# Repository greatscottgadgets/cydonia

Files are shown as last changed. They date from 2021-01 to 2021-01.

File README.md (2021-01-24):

# Cydonia

a 2.4 GHz receiver front-end based on [Quince](https://github.com/greatfet-hardware/quince)

## Project Status

Initial prototypes have not yet been assembled.

## Viewing or Modifying the Design

Required KiCad dependency:

https://github.com/greatscottgadgets/gsg-kicad-lib

If you are using git, the preferred way to install gsg-kicad-lib is to use the
submodule:

```
git submodule init && git submodule update
```

## Hardware Development Notes

See [Quince](https://github.com/greatfet-hardware/quince).

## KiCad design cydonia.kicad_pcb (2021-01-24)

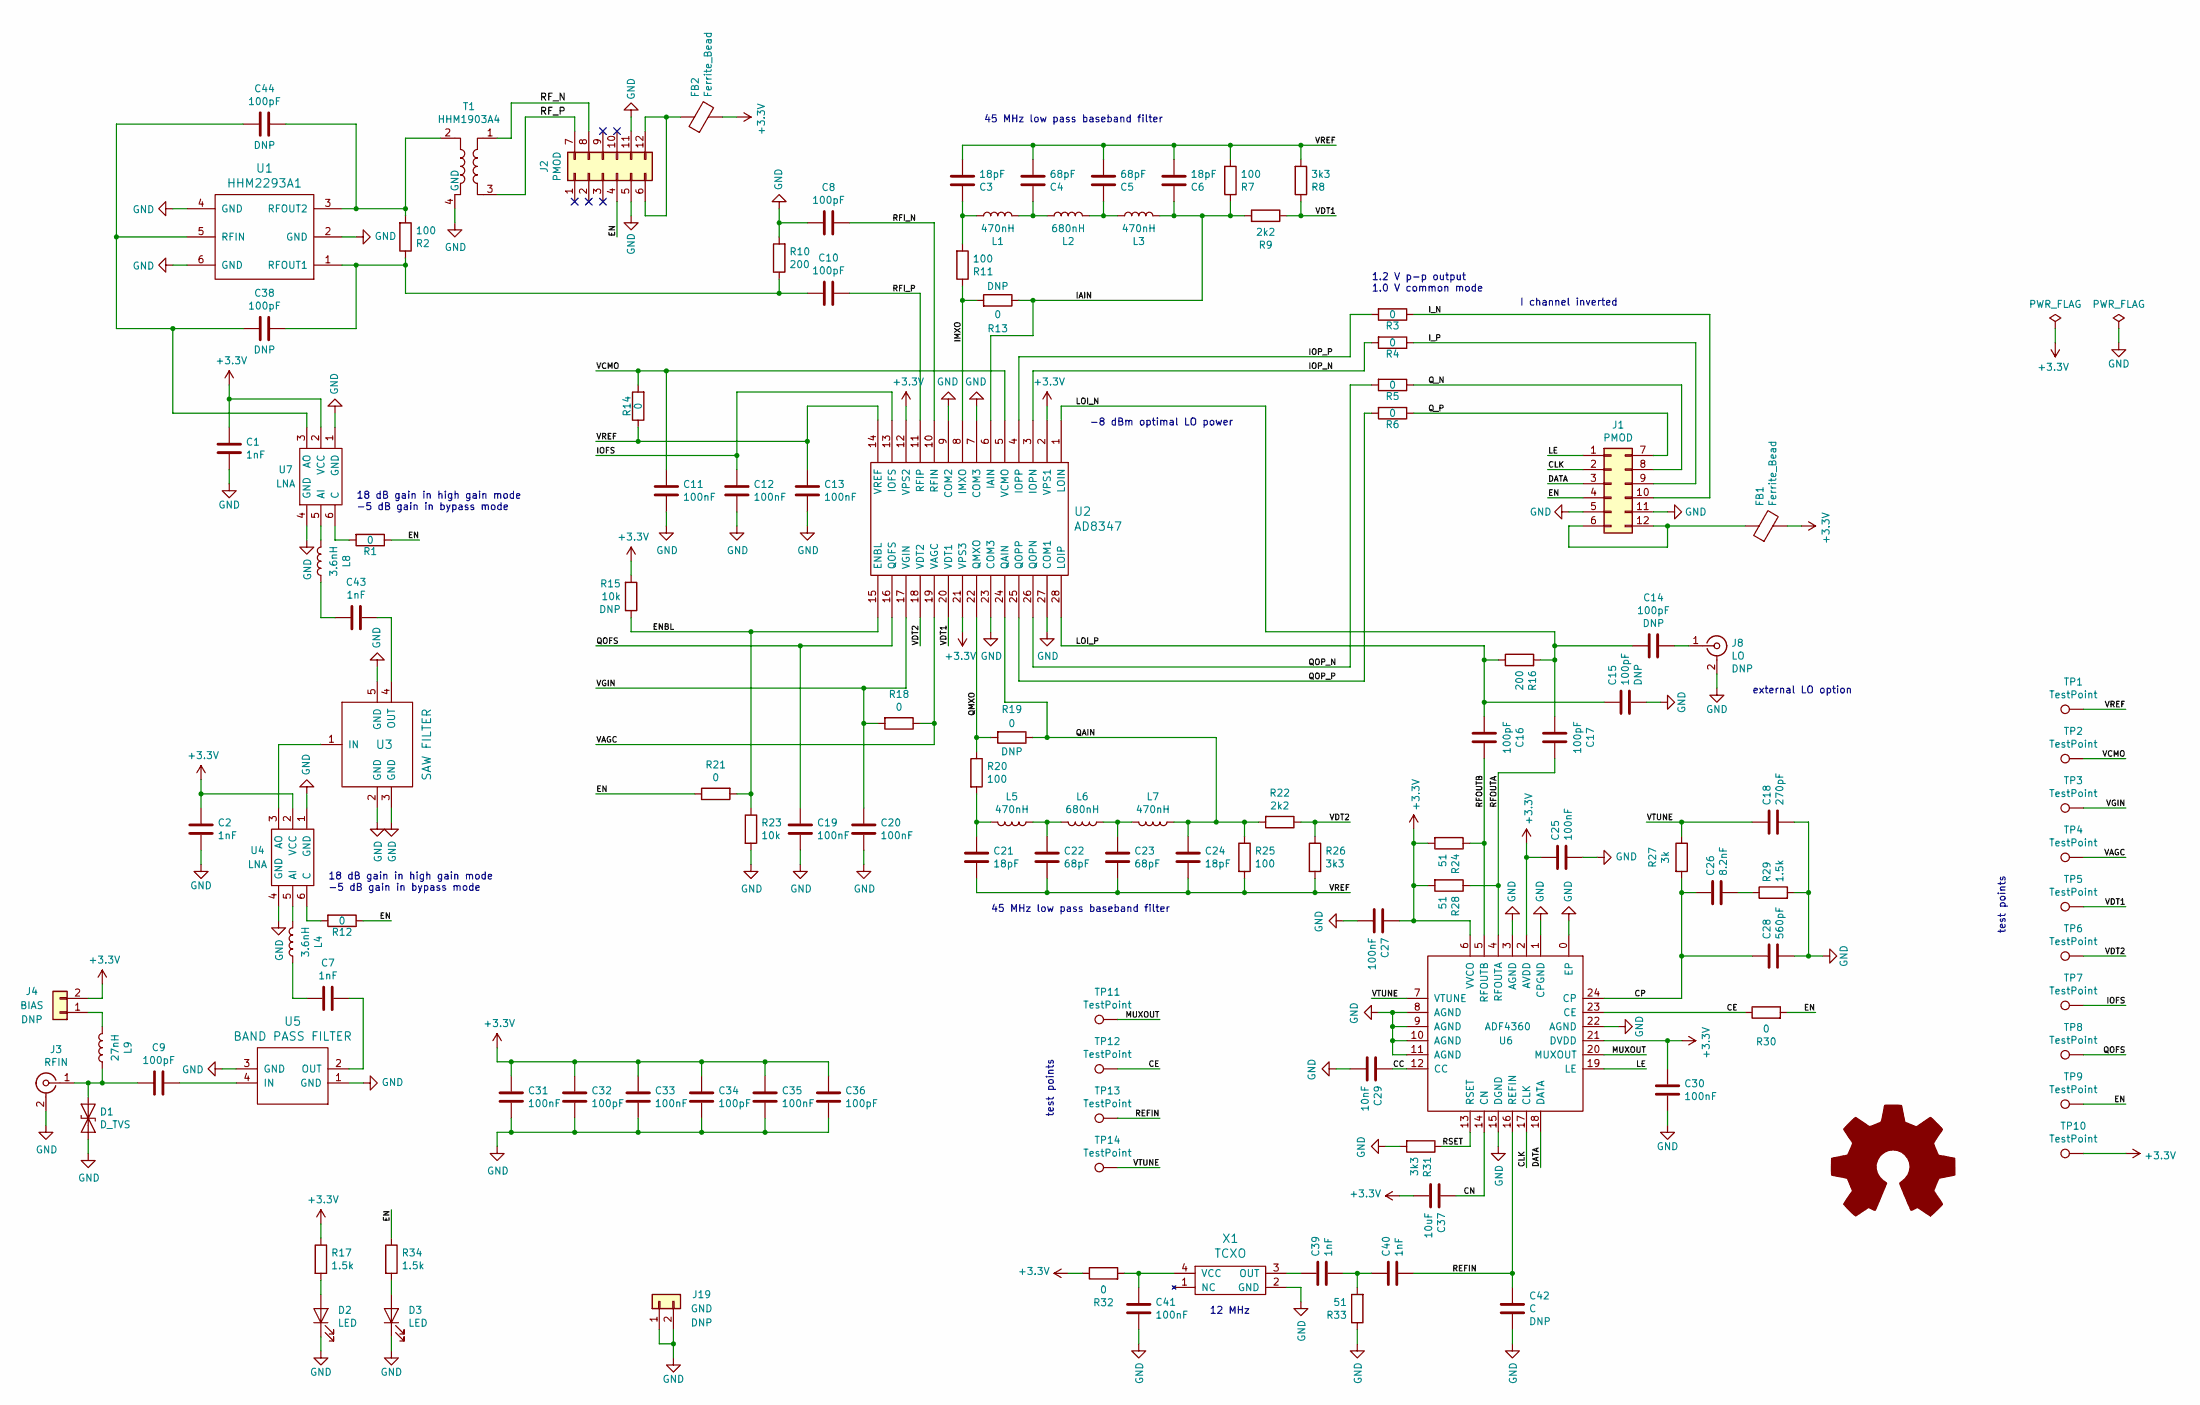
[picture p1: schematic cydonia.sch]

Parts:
C1, C2, C7, C39, C40, C43: 1nF; 0402; Part Number UMK105B7102KV-F
C3, C6, C21, C24: 18pF; 0402; Part Number CC0402JRNPO9BN180
C4, C5, C22, C23: 68pF; 0402; Part Number CL05C680JB5NNNC
C8, C9, C10, C14, C15, C16, C17, C32, C34, C36, C38, C44: 100pF; 0402; Part Number CL05C101JB5NNNC
C11, C12, C13, C19, C20, C25, C27, C30, C31, C33, C35, C41: 100nF; 0402; Part Number ‎CL05A104KP5NNNC‎
C18: 270pF; 0402; Part Number CC0402KRX7R9BB271
C26: 8.2nF; 0402; Part Number CC0402KRX7R7BB822
C28: 560pF; 0402; Part Number CC0402KRX7R8BB561
C29: 10nF; 0402; Part Number CL05B103KB5NNNC
C37: 10uF; 0805; Part Number CL21A106KPFNNNG
C42: C; 0402
D1: D_TVS; 0402; Part Number ESDSLC5V0L2B-TP
D2, D3: LED; 0603D
FB1, FB2: Ferrite_Bead; 0805; Part Number BLM21PG221SN1D
J1, J2: PMOD; PinHeader_2x06_P2.54mm_PMOD; Part Number PPPC062LJBN-RC
J3: RFIN; SMA-EDGE; Part Number CONREVSMA003.062
J4: BIAS; HEADER-1x2
J8: LO; SMA-VERTICAL; Part Number 5-1814832-1
J19: GND; HEADER-1x2
L1, L3, L5, L7: 470nH; 0402; Part Number LK1005R47K-TV
L2, L6: 680nH; 0402; Part Number LK1005R68K-TV
L4, L8: 3.6nH; 0402; Part Number HK10053N6S-T
L9: 27nH; 0402; Part Number HK100527NJ-T
R1, R3, R4, R5, R6, R12, R13, R14, R18, R19, R21, R30, R32: 0; 0402; Part Number RC0402JR-070RL
R2, R7, R11, R20, R25: 100; 0402; Part Number RC0402JR-07100RL
R8, R26, R31: 3k3; 0402; Part Number RC0402JR-073K3L
R9, R22: 2k2; 0402; Part Number RC0402JR-072K2L
R10, R16: 200; 0402; Part Number RC0402JR-07200RL
R15, R23: 10k; 0402; Part Number RC0402JR-0710KL
R17, R29, R34: 1.5k; 0402; Part Number RC0402JR-071K5L
R24, R28, R33: 51; 0402; Part Number RC0402JR-0751RL
R27: 3k; 0402; Part Number RC0402JR-073KL
T1: HHM1903A4; Part Number HHM1903A4
TP1, TP2, TP3, TP4, TP5, TP6, TP7, TP8, TP9, TP10, TP11, TP12, TP13, TP14: TestPoint; TESTPOINT-50MIL
U1: HHM2293A1; Part Number HHM2293A1
U2: AD8347; TSSOP28; Part Number AD8347ARUZ-REEL7
U3: SAW FILTER; B9413; Part Number B39242B9413K610
U4, U7: LNA; BGA7H1N6; Part Number BGA5H1BN6E6327XTSA1
U5: BAND PASS FILTER; 2450BP39D100C; Part Number 2450BP39D100CE
U6: ADF4360; QFN24-4; Part Number ADF4360-0BCPZ
X1: TCXO; XTAL5.0x3.2mm; Part Number FT5HNBPK12.0-T1

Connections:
+3V3: C1.2, C2.2, C25.1, C27.1, C30.1, C31.1, C32.2, C33.1, C34.2, C35.1, C36.2, C37.2, FB1.2, FB2.2, J4.2, R15.2, R17.1, R24.2, R28.2, R32.1, TP10.1, U2.2 (VPS1), U2.12 (VPS2), U2.21 (VPS3), U4.2 (VCC), U6.2 (AVDD), U6.6 (VVCO), U6.21 (DVDD), U7.2 (VCC)
/CC: C29.1, U6.12 (CC)
/CE: R30.1, TP12.1, U6.23 (CE)
/CLK: J1.2, U6.17 (CLK)
/CN: C37.1, U6.14 (CN)
/CP: C26.2, C28.2, R27.2, U6.24 (CP)
/DATA: J1.3, U6.18 (DATA)
/EN: J1.4, J2.4, R1.1, R12.1, R21.1, R30.2, R34.1, TP9.1
/ENBL: R15.1, R21.2, R23.1, U2.15 (ENBL)
/IAIN: C6.1, L3.1, R7.1, R9.2, R13.1, U2.6 (IAIN)
/IMXO: R11.1, R13.2, U2.8 (IMXO)
/IOFS: C12.1, TP7.1, U2.13 (IOFS)
/IOP_N: R4.2, U2.3 (IOPN)
/IOP_P: R3.2, U2.4 (IOPP)
/I_N: J1.10, R3.1
/I_P: J1.9, R4.1
/LE: J1.1, U6.19 (LE)
/LOI_N: C14.2, C17.2, R16.2, U2.1 (LOIN)
/LOI_P: C15.2, C16.2, R16.1, U2.28 (LOIP)
/MUXOUT: TP11.1, U6.20 (MUXOUT)
/QAIN: C24.1, L7.1, R19.1, R22.2, R25.1, U2.24 (QAIN)
/QMXO: R19.2, R20.1, U2.22 (QMXO)
/QOFS: C19.1, TP8.1, U2.16 (QOFS)
/QOP_N: R5.2, U2.26 (QOPN)
/QOP_P: R6.2, U2.25 (QOPP)
/Q_N: J1.8, R5.1
/Q_P: J1.7, R6.1
/REFIN: C40.2, C42.2, TP13.1, U6.16 (REFIN)
/RFI_N: C8.1, U2.10 (RFIN)
/RFI_P: C10.1, U2.11 (RFIP)
/RFOUTA: C17.1, R28.1, U6.4 (RFOUTA)
/RFOUTB: C16.1, R24.1, U6.5 (RFOUTB)
/RF_N: J2.8, T1.1
/RF_P: J2.7, T1.3
/RSET: R31.1, U6.13 (RSET)
/VAGC: R18.1, TP4.1, U2.19 (VAGC)
/VCMO: C11.1, R14.2, TP2.1, U2.5 (VCMO)
/VDT1: R8.1, R9.1, TP5.1, U2.20 (VDT1)
/VDT2: R22.1, R26.1, TP6.1, U2.18 (VDT2)
/VGIN: C20.1, R18.2, TP3.1, U2.17 (VGIN)
/VREF: C3.2, C4.2, C5.2, C6.2, C13.1, C21.2, C22.2, C23.2, C24.2, R7.2, R8.2, R14.1, R25.2, R26.2, TP1.1, U2.14 (VREF)
/VTUNE: C18.2, R27.1, TP14.1, U6.7 (VTUNE)
GND: C1.1, C2.1, C8.2, C11.2, C12.2, C13.2, C15.1, C18.1, C19.2, C20.2, C25.2, C27.2, C28.1, C29.2, C30.2, C31.2, C32.1, C33.2, C34.1, C35.2, C36.1, C41.2, C42.1, D1.2 (A2), D2.1 (K), D3.1 (K), J1.5, J1.11, J2.5, J2.11, J3.2 (Ext), J8.2 (Ext), J19.1, J19.2, R10.2, R23.2, R29.2, R31.2, R33.1, T1.4 (GND), U1.2 (GND), U1.4 (GND), U1.6 (GND), U2.7 (COM3), U2.9 (COM2), U2.23 (COM3), U2.27 (COM1), U3.2 (GND), U3.3 (GND), U3.5 (GND), U4.1 (GND), U4.4 (GND), U5.1 (GND), U5.3 (GND), U6.0 (EP), U6.1 (CPGND), U6.3 (AGND), U6.8 (AGND), U6.9 (AGND), U6.10 (AGND), U6.11 (AGND), U6.15 (DGND), U6.22 (AGND), U7.1 (GND), U7.4 (GND), X1.2 (GND)
unnamed: C3.1, L1.2, R11.2
unnamed: C4.1, L1.1, L2.2
unnamed: C5.1, L2.1, L3.2
unnamed: C7.1, L4.2
unnamed: C7.2, U5.2 (OUT)
unnamed: C9.1, U5.4 (IN)
unnamed: C9.2, D1.1 (A1), J3.1 (In), L9.2
unnamed: C10.2, C38.1, R2.1, R10.1, U1.1 (RFOUT1)
unnamed: C14.1, J8.1 (In)
unnamed: C21.1, L5.2, R20.2
unnamed: C22.1, L5.1, L6.2
unnamed: C23.1, L6.1, L7.2
unnamed: C26.1, R29.1
unnamed: C38.2, C44.2, U1.5 (RFIN), U7.3 (AO)
unnamed: C39.1, X1.3 (OUT)
unnamed: C39.2, C40.1, R33.2
unnamed: C41.1, R32.2, X1.4 (VCC)
unnamed: C43.1, L8.2
unnamed: C43.2, U3.4 (OUT)
unnamed: C44.1, R2.2, T1.2, U1.3 (RFOUT2)
unnamed: D2.2 (A), R17.2
unnamed: D3.2 (A), R34.2
unnamed: FB1.1, J1.6, J1.12
unnamed: FB2.1, J2.6, J2.12
unnamed: J4.1, L9.1
unnamed: L4.1, U4.5 (AI)
unnamed: L8.1, U7.5 (AI)
unnamed: R1.2, U7.6 (C)
unnamed: R12.2, U4.6 (C)
unnamed: U3.1 (IN), U4.3 (AO)

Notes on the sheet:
45 MHz low pass baseband filter
1.2 V p-p output 1.0 V common mode
external LO option
-8 dBm optimal LO power
test points
12 MHz
I channel inverted
18 dB gain in high gain mode -5 dB gain in bypass mode

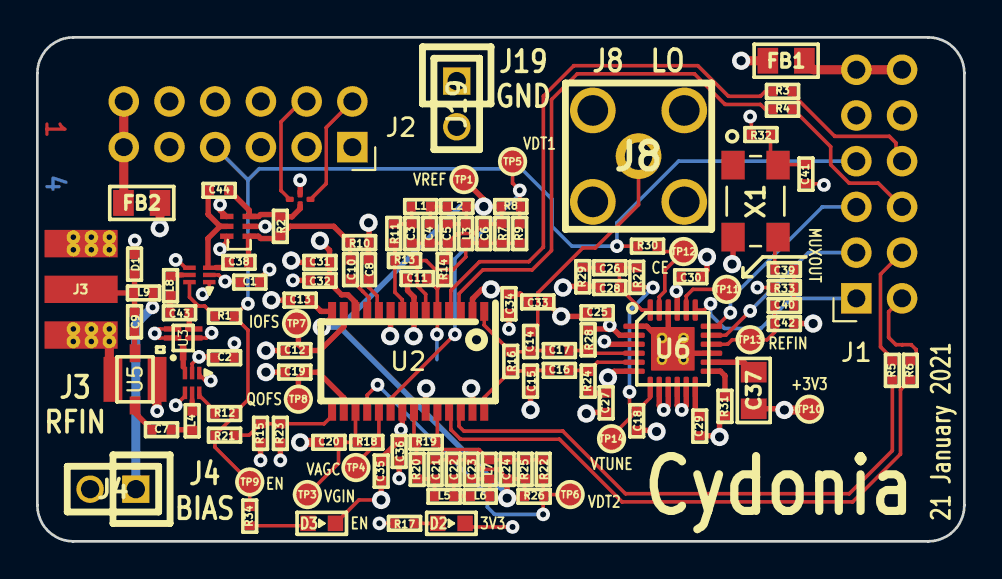
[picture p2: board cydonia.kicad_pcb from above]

Board: 4 copper layers, 51.5 x 28.0 mm, 121 parts (1 on the bottom side), 73 nets.

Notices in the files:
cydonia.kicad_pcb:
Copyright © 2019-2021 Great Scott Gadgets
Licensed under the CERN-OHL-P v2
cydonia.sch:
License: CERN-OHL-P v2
